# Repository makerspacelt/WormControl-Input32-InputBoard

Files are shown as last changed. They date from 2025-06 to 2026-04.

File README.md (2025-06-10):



---
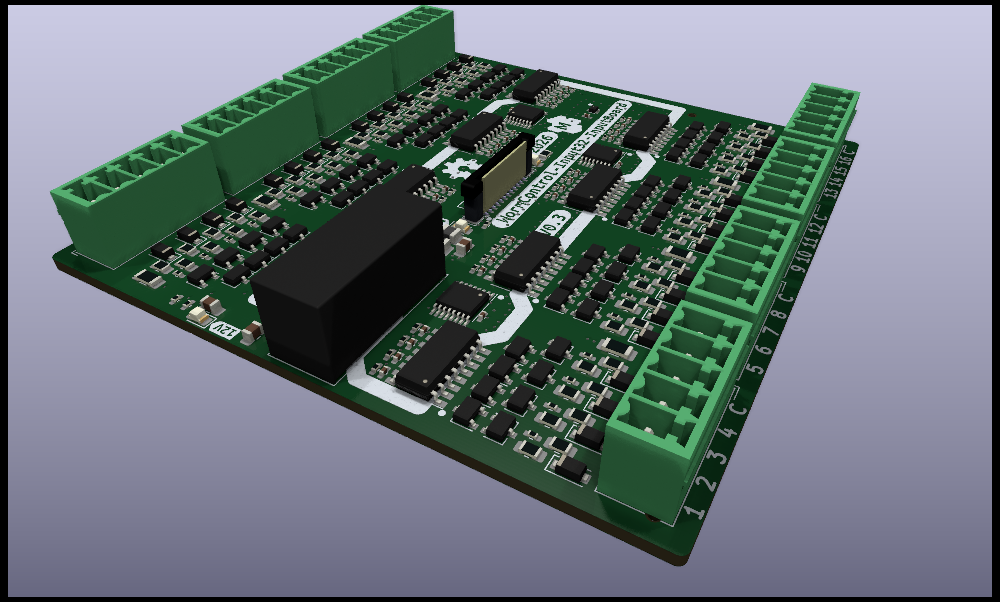
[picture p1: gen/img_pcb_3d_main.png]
PCB 3d main


WormControl Input32 InputBoard

NOTE: This is only a prototype now, so things might not work and everything might change 

Basic target features:

* 32 optically isolated binary inputs
* some kind of serial bus comunication
* 24V powered

Dev NOTE: before commit, run `./kibot.sh` to regenerate documentation, bom, gerbers and other assets.

* [schematics.pdf](gen/schematics.pdf)
* [pcb.pdf with dimensions](gen/pcb.pdf)
* [ibom.html](gen/single/ibom.html)

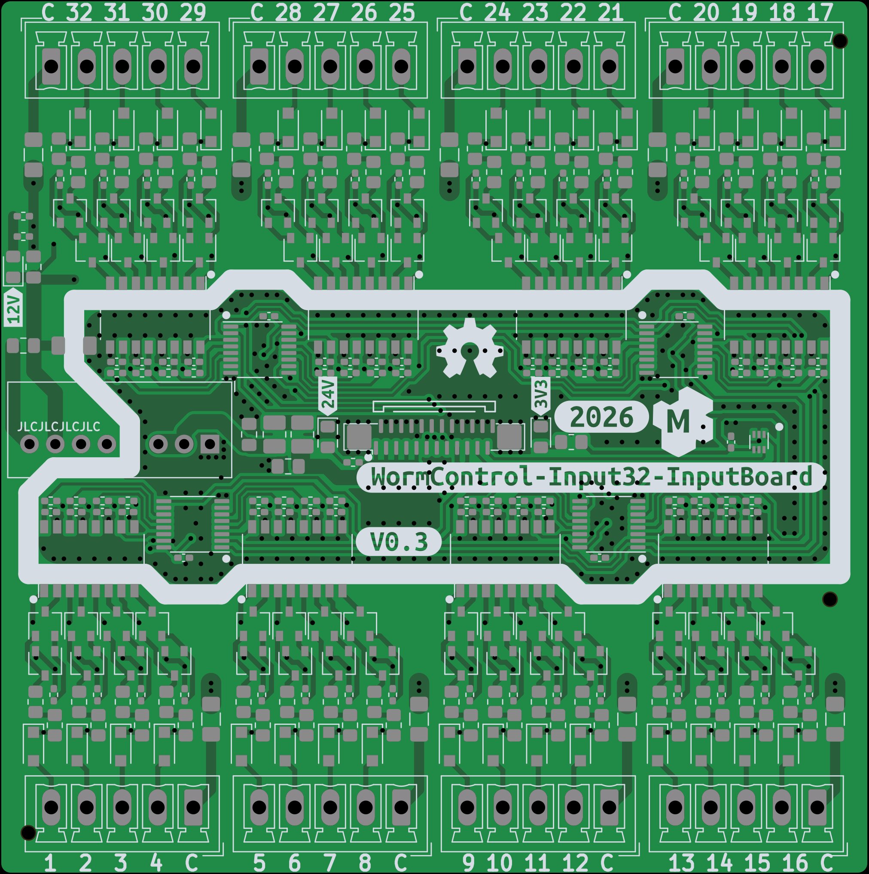
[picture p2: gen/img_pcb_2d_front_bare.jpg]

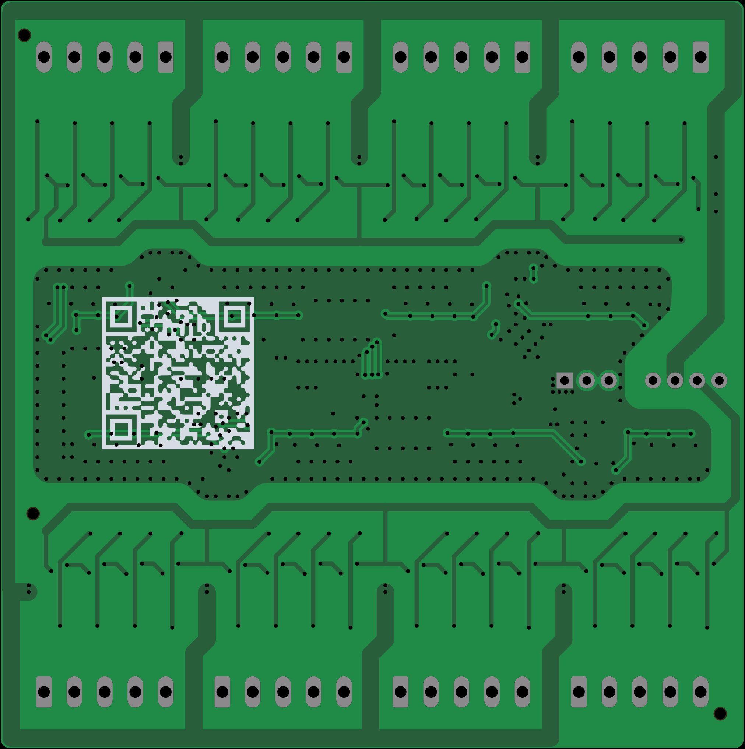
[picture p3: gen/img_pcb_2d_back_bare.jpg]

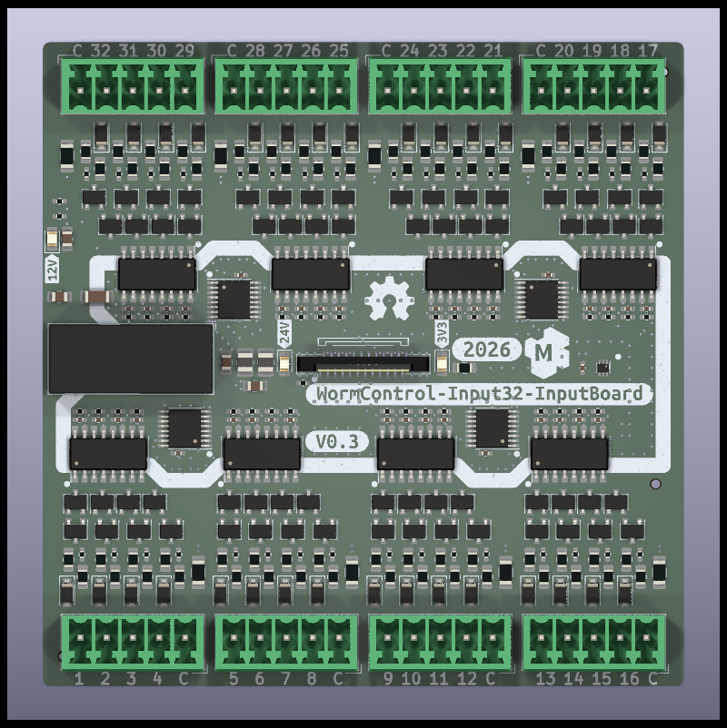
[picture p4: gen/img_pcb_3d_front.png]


---

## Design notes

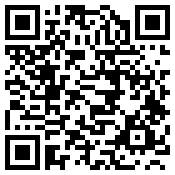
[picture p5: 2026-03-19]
gen/qr_link.png

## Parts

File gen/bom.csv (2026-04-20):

Row | Description | Part | References | Value | Footprint | Quantity Per PCB | Status | Datasheet | jlc-part-type | lcsc#
1 | Heatsink | Heatsink | BOM2,BOM3,BOM4,BOM5,BOM6,BOM7,BOM8,BOM9 | 1x5 screw plug |  | 8 |  | ~ | E | C560233
2 | Heatsink | Heatsink | BOM1 | FFC Cable 150mm reverse |  | 1 |  | https://www.lcsc.com/datasheet/C42434316.pdf | E | C42434316
3 | Unpolarized capacitor | C | C1,C2,C3,C4,C5,C6,C7,C8,C9,C10,C11,C12,C13,C14,C15,C16,C17,C18,C19,C20,C21,C22,C23,C24,C25,C26,C27,C28,C29,C30,C31,C32,C33,C39,C40,C41,C42 | 100n | C_0402_1005Metric_Pad0.74x0.62mm_HandSolder | 37 |  | ~ | B | C307331
4 | Unpolarized capacitor | C | C34,C35 | 10u/50v | C_0805_2012Metric_Pad1.18x1.45mm_HandSolder | 2 |  | ~ | B | C440198
5 | Unpolarized capacitor | C | C36 | 1n/2KV | C_1206_3216Metric_Pad1.33x1.80mm_HandSolder | 1 |  | ~ | B | C9196
6 | Unpolarized capacitor | C | C37,C38 | 22u/25v | C_0805_2012Metric_Pad1.18x1.45mm_HandSolder | 2 |  | ~ | B | C45783
7 | Light emitting diode | LED | D1,D30,D31 | GREEN | LED_0805_2012Metric_Pad1.15x1.40mm_HandSolder | 3 |  | ~ | B | C2297
8 | Diode, small symbol | D_Small | D2,D3,D4,D5,D6,D7,D8,D9,D10,D11,D12,D13,D14,D15,D16,D17,D18,D19,D20,D21,D22,D23,D24,D25,D26,D27,D28,D29,D32,D33,D34,D35 | SM4007PL | D_SOD-123F | 32 |  | ~ | B | C64898
9 | Resettable fuse, polymeric positive temperature coefficient | Polyfuse | F1,F2,F3,F4,F5,F6,F7,F8 | 50mA | Fuse_1206_3216Metric_Pad1.42x1.75mm_HandSolder | 8 |  | ~ | E | C2830235
10 | Generic connectable mounting pin connector, single row, 01x24, script generated (kicad-library-utils/schlib/autogen/connector/) | Conn_01x24_MountingPin | J1 | FFC Connector | AFC11-S24ICC-00 | 1 |  | ~ | E | C11075
11 | Generic screw terminal, single row, 01x05, script generated (kicad-library-utils/schlib/autogen/connector/) | Screw_Terminal_01x05 | J2,J3,J4,J5,J6,J7,J8,J9 | input_1x5 | PhoenixContact_MCV_1,5_5-G-3.5_1x05_P3.50mm_Vertical | 8 |  | ~ | E | C880557
12 | Inductor | L | L1,L2 | 3.3uH | L_1008_2520Metric_Pad1.43x2.20mm_HandSolder | 2 |  | ~ | E | C206304
13 | 3W, 1000 VDC Isolated DC/DC Converter Module, Remote Control, 24v in 12v out | 2412S-3WR2 | PS1 | 2412S-3WR2 | Converter_DCDC_XP_POWER-ITxxxxxS_THT | 1 |  | https://www.lcsc.com/datasheet/lcsc_datasheet_2410161204_YLPTEC-URB2412S-3WR2_C22749764.pdf | N | C22749764
14 | NPN transistor, base/emitter/collector | Q_NPN_BEC | Q1,Q2,Q3,Q4,Q5,Q6,Q7,Q8,Q9,Q10,Q11,Q12,Q13,Q14,Q15,Q16,Q17,Q18,Q19,Q20,Q21,Q22,Q23,Q24,Q25,Q26,Q27,Q28,Q29,Q30,Q31,Q32,Q33,Q34,Q35,Q36,Q37,Q38,Q39,Q40,Q41,Q42,Q43,Q44,Q45,Q46,Q47,Q48,Q49,Q50,Q51,Q52,Q53,Q54,Q55,Q56,Q57,Q58,Q59,Q60,Q61,Q62,Q63,Q64 | MMBTA44 | SOT-23W | 64 |  | ~ | E | C5381782
15 | Resistor | R | R10,R11,R12,R13,R26,R27,R28,R29,R42,R43,R44,R45,R58,R59,R60,R61,R74,R75,R76,R77,R90,R91,R92,R93,R106,R107,R108,R109,R125,R126,R127,R128 | 330R | R_0402_1005Metric_Pad0.72x0.64mm_HandSolder | 32 |  | ~ | B | C25104
16 | Resistor | R | R1 | 4k7 | R_0805_2012Metric_Pad1.20x1.40mm_HandSolder | 1 |  | ~ | B | C17673
17 | Resistor | R | R14,R15,R16,R17,R30,R31,R32,R33,R46,R47,R48,R49,R62,R63,R64,R65,R78,R79,R80,R81,R94,R95,R96,R97,R110,R111,R112,R113,R114,R115,R116,R129,R130,R131,R132 | 47k | R_0402_1005Metric_Pad0.72x0.64mm_HandSolder | 35 |  | ~ | B | C25792
18 | Resistor | R | R2,R3,R4,R5,R6,R7,R8,R9,R18,R19,R20,R21,R22,R23,R24,R25,R34,R35,R36,R37,R38,R39,R40,R41,R50,R51,R52,R53,R54,R55,R56,R57,R66,R67,R68,R69,R70,R71,R72,R73,R82,R83,R84,R85,R86,R87,R88,R89,R98,R99,R100,R101,R102,R103,R104,R105,R117,R118,R119,R120,R121,R122,R123,R124 | 220k | R_0805_2012Metric_Pad1.20x1.40mm_HandSolder | 64 |  | ~ | B | C17556
19 | Shift Register, 8-bit, Parallel Load | 74HC165 | U1,U2,U4,U5 | 74HC165 | TSSOP-16_4.4x5mm_P0.65mm | 4 |  | https://assets.nexperia.com/documents/data-sheet/74HC_HCT165.pdf | E | C26159248
20 | Quad AC/DC Optocoupler, Vce 35V, CTR 20%, DIP16 | LTV-844 | U6,U7,U8,U9,U10,U11,U12,U13 | LTV-244-GB-G | SOP-16_4.4x10.4mm_P1.27mm | 8 |  | https://jlcpcb.com/api/file/downloadByFileSystemAccessId/8589836176828751872 | E | C5143796
21 | Digital Temperature Sensor, +/- 3 °C, low-Power, SMBus, 12 bit, Two-Wire Serial Interface, SOT-563 | TMP102xxDRL | U3 | TMP102 | SOT-563 | 1 |  | https://www.ti.com/lit/ds/symlink/tmp102.pdf | E | C99269

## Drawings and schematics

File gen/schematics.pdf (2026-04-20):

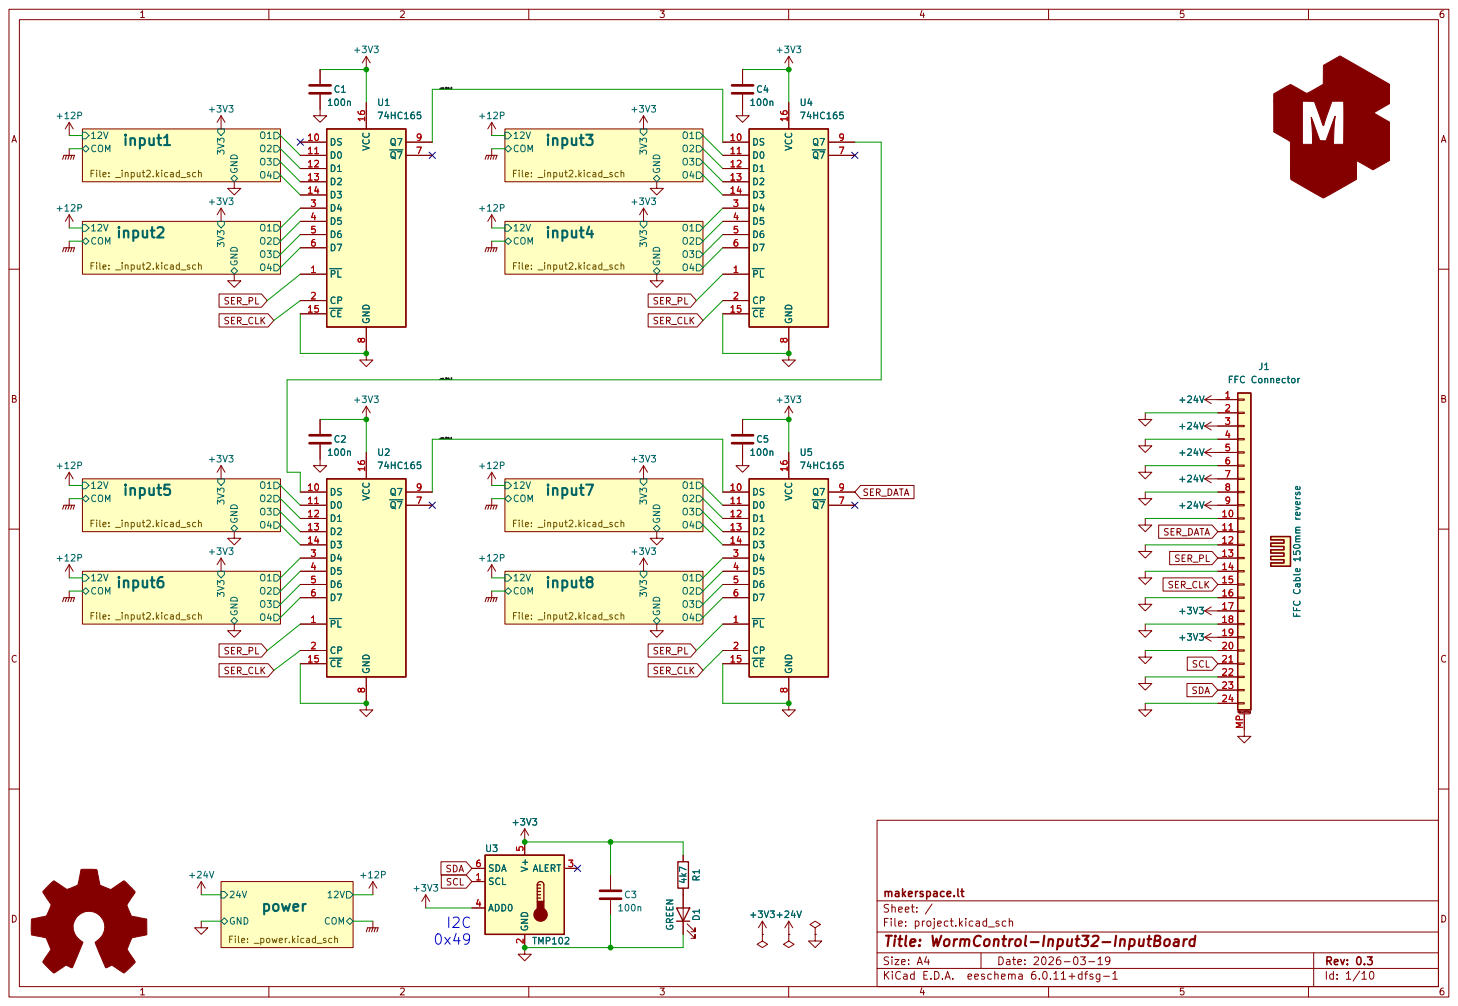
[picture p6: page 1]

Id: 1/10 Title: WormControl-Input32-InputBoard

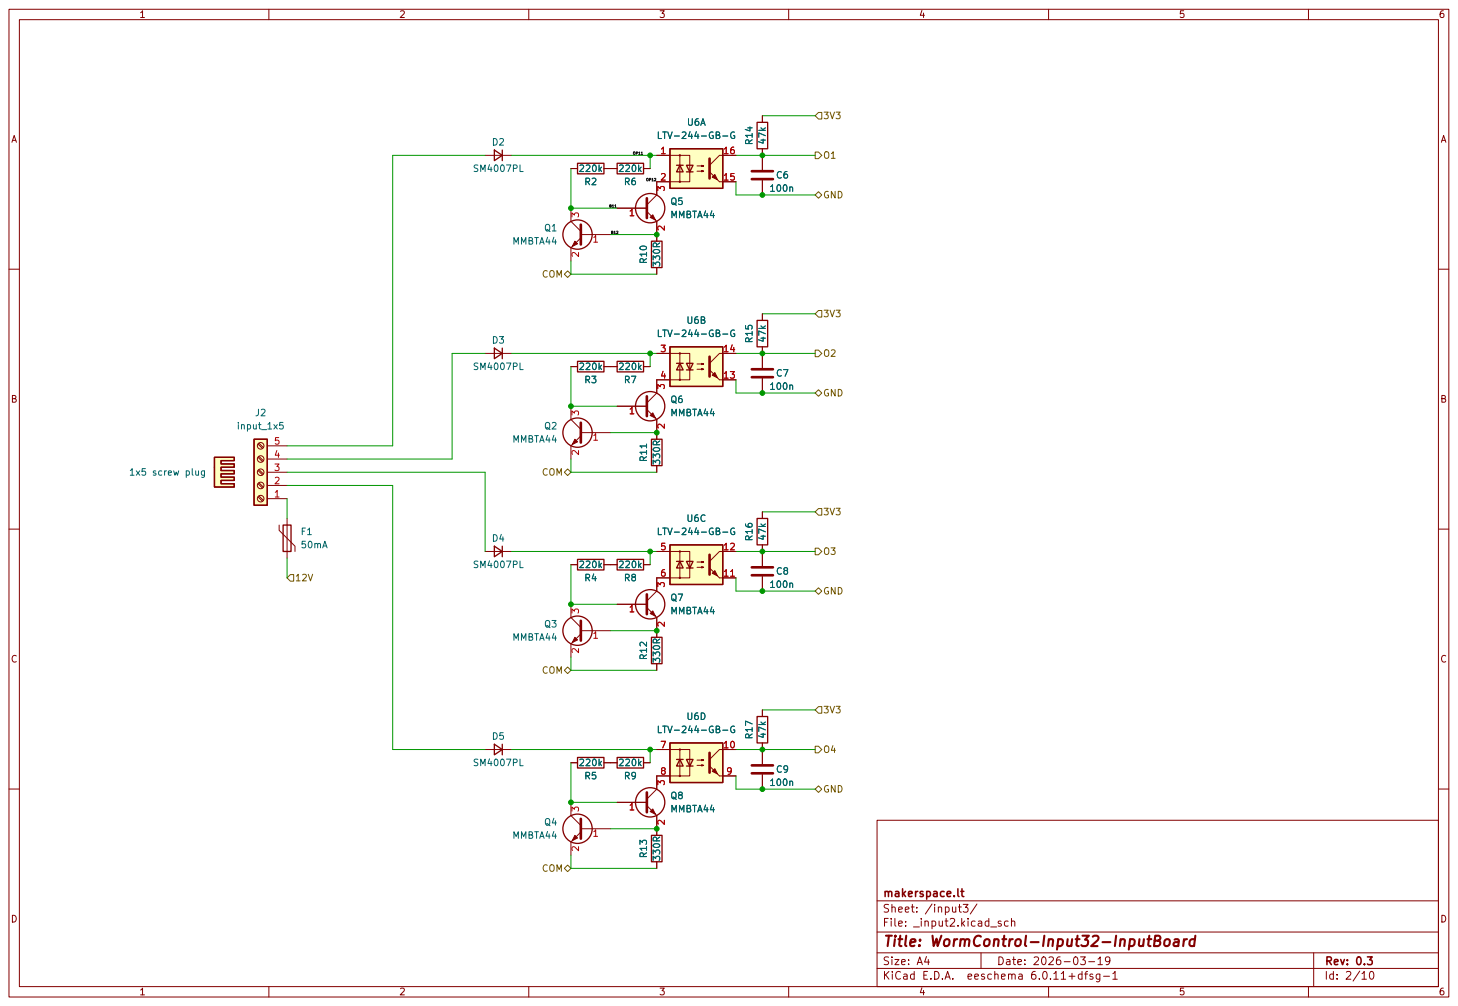
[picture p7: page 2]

File: _input2.kicad_sch Sheet: /input3/
Id: 2/10 Title: WormControl-Input32-InputBoard

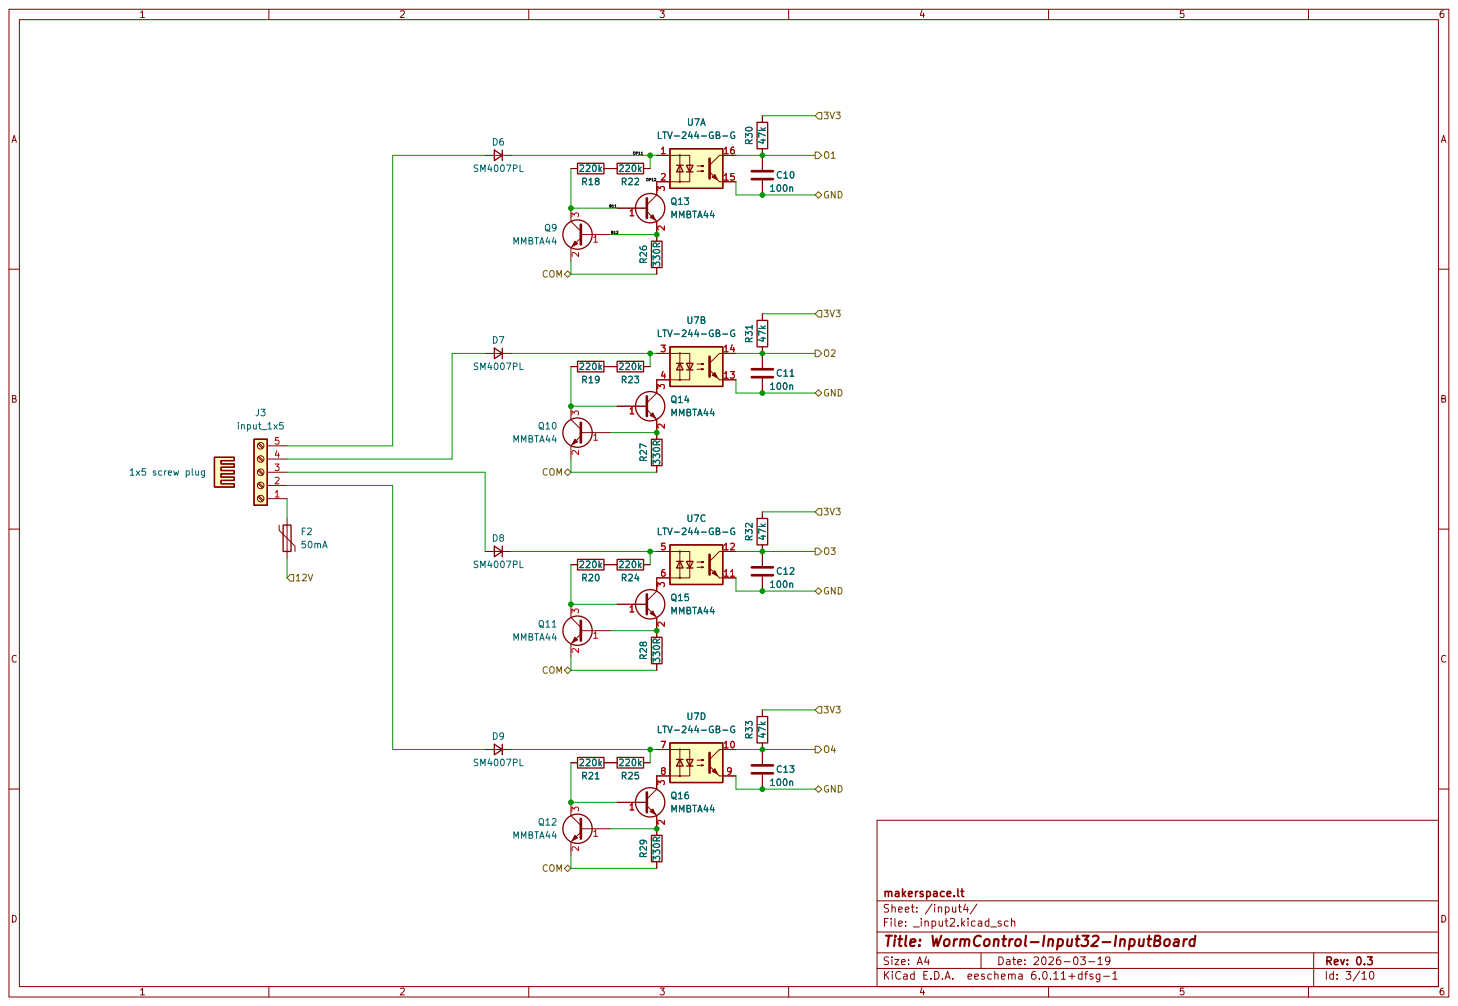
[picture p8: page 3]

makerspace.lt
File: _input2.kicad_sch Sheet: /input4/
Id: 3/10 Title: WormControl-Input32-InputBoard

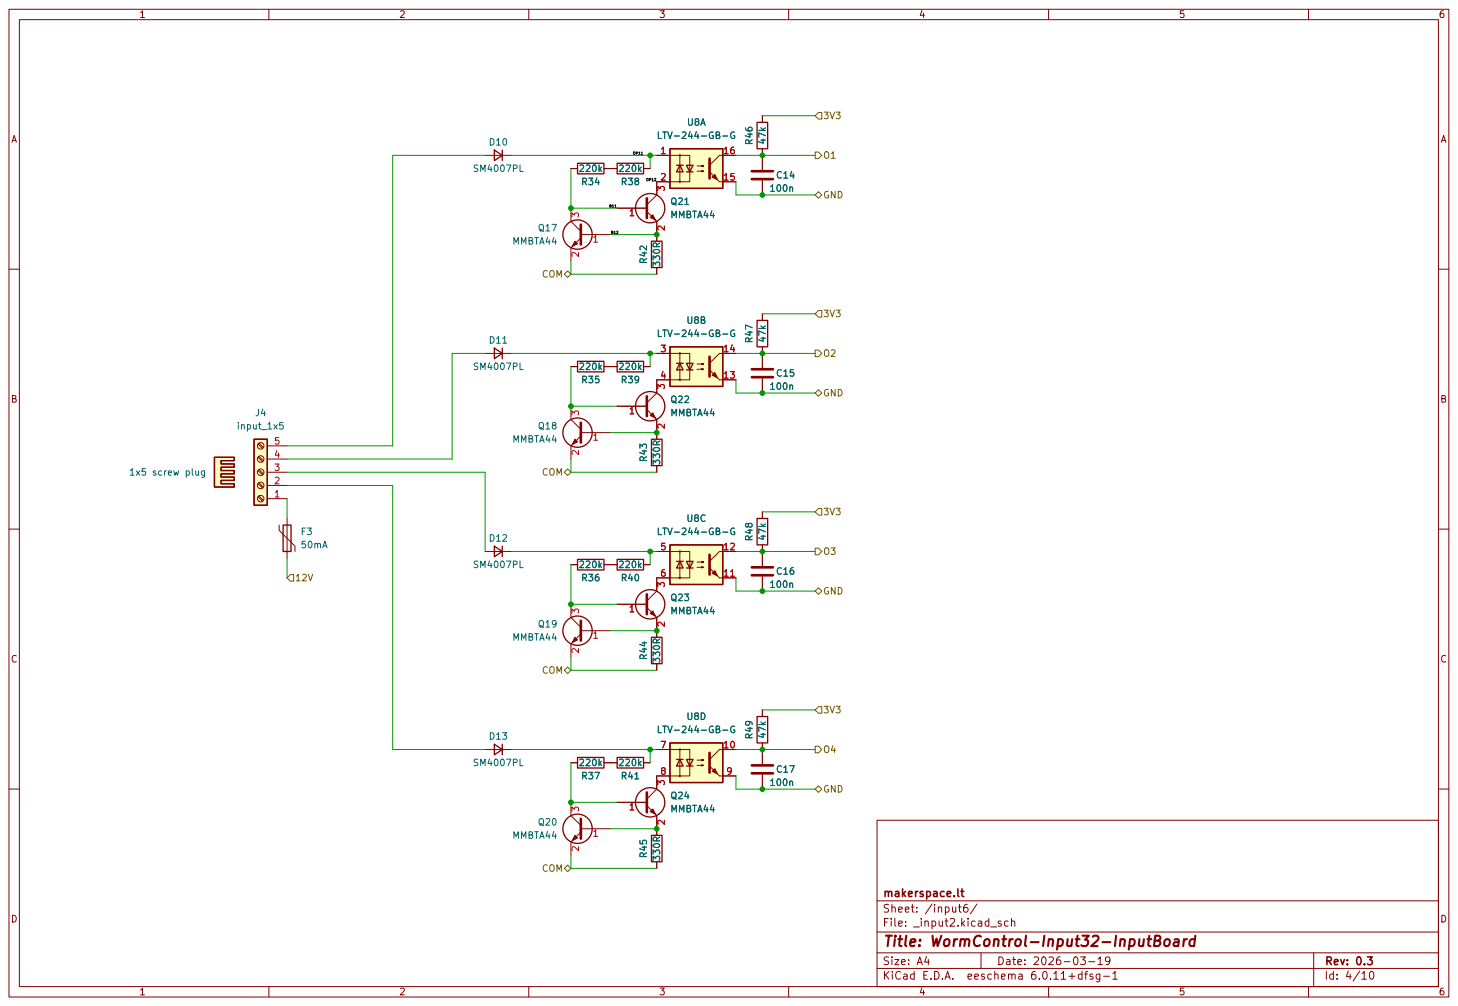
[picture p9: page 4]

makerspace.lt
File: _input2.kicad_sch Sheet: /input6/
Id: 4/10 Title: WormControl-Input32-InputBoard

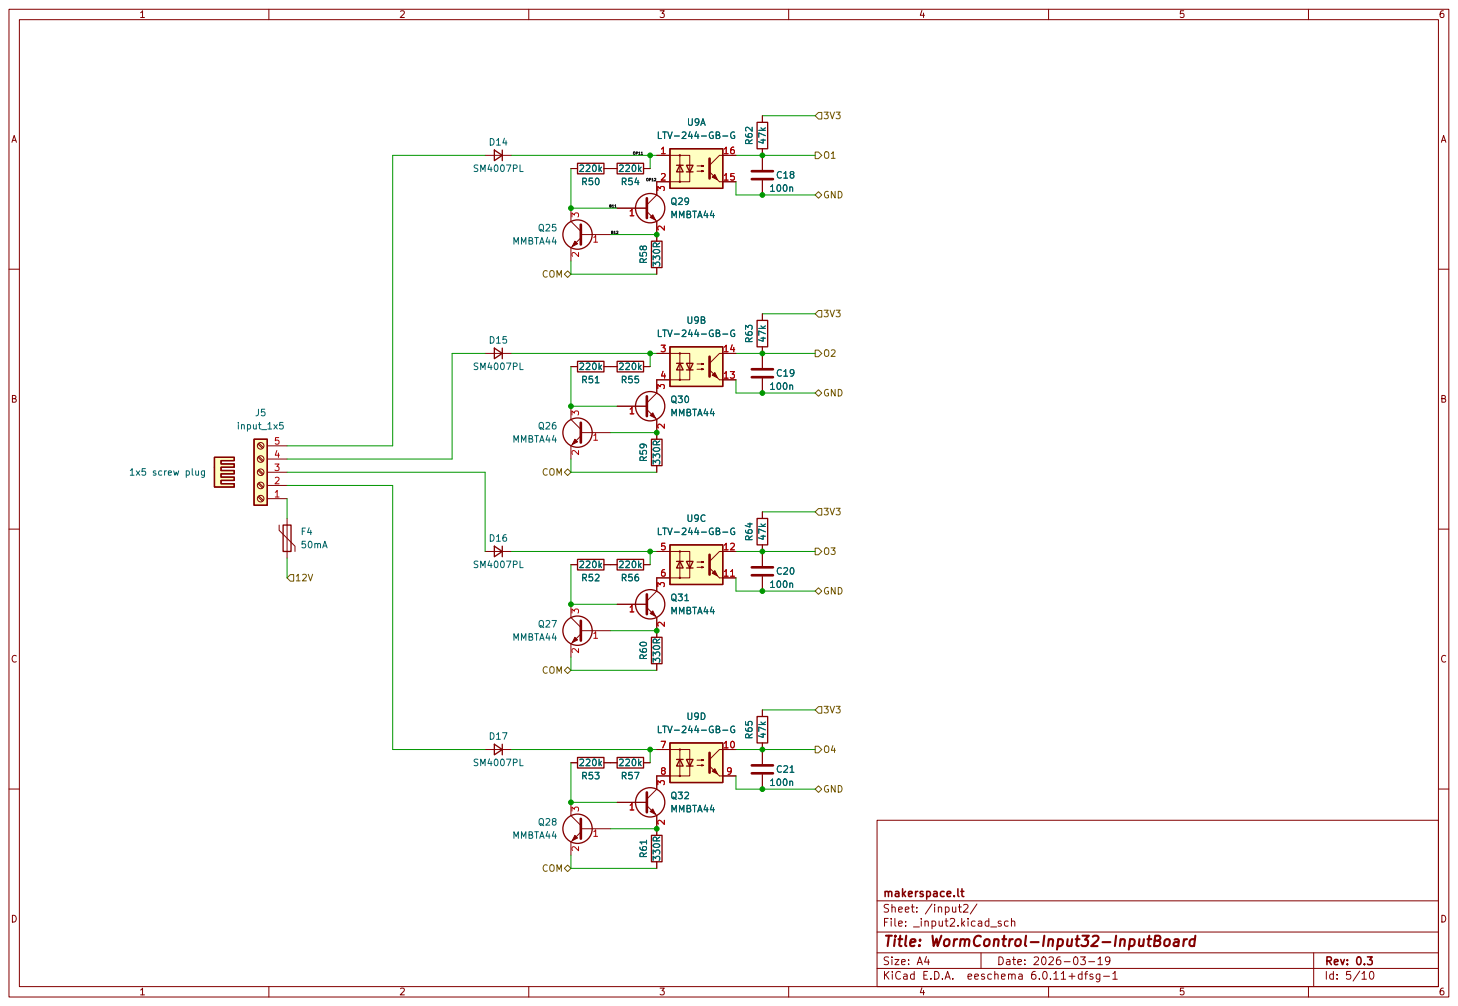
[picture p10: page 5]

makerspace.lt
File: _input2.kicad_sch Sheet: /input2/
Id: 5/10 Title: WormControl-Input32-InputBoard

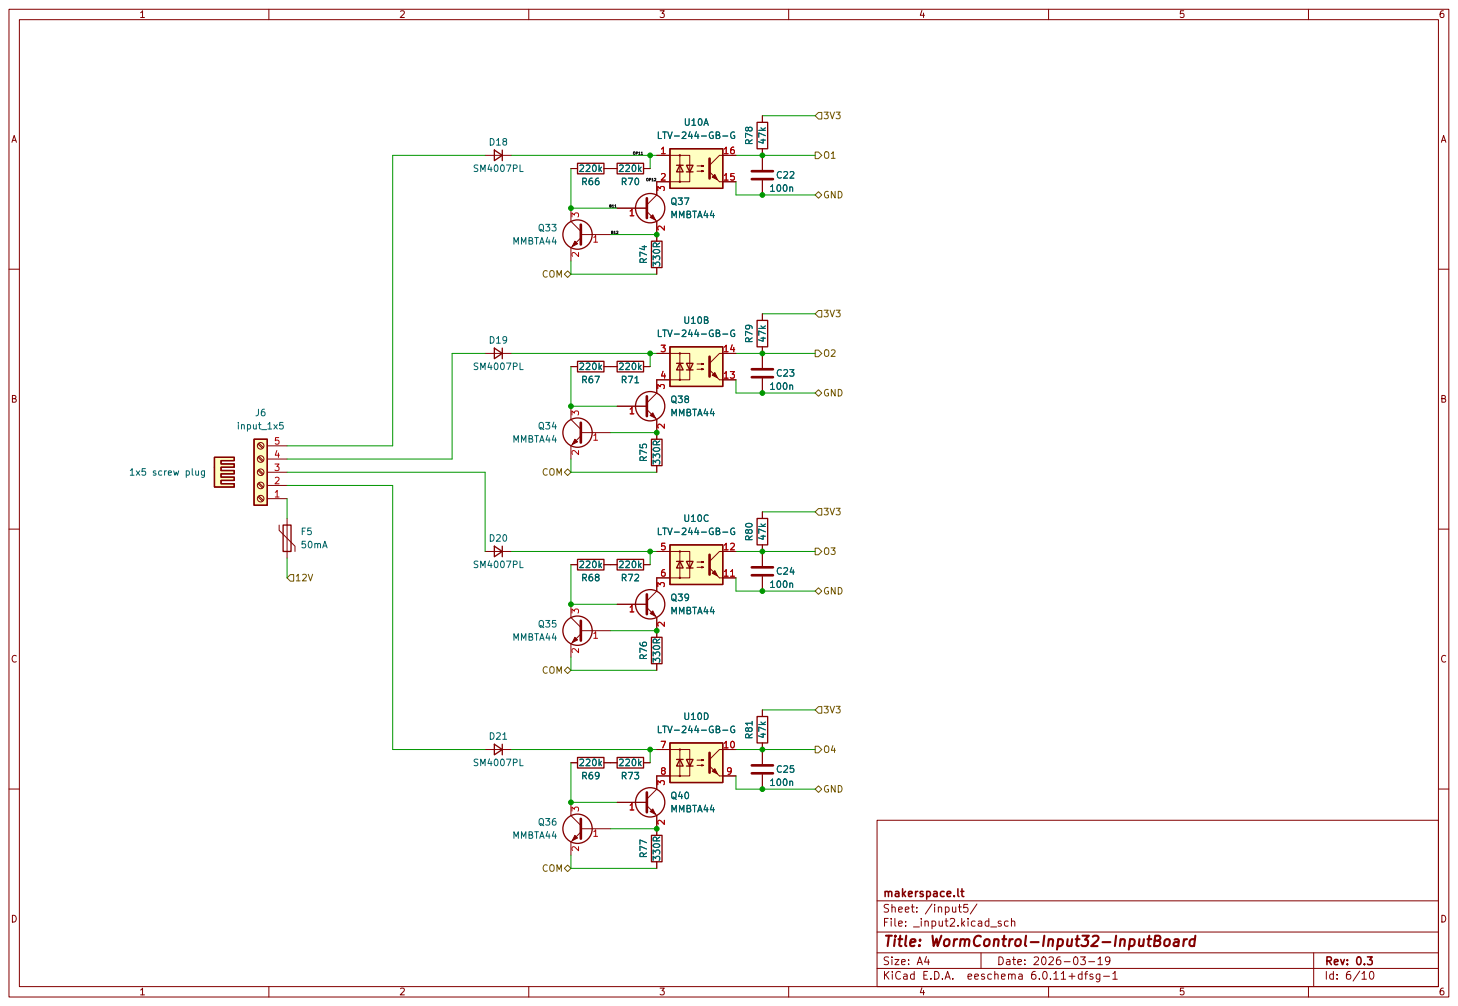
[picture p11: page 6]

makerspace.lt
File: _input2.kicad_sch Sheet: /input5/
Id: 6/10 Title: WormControl-Input32-InputBoard

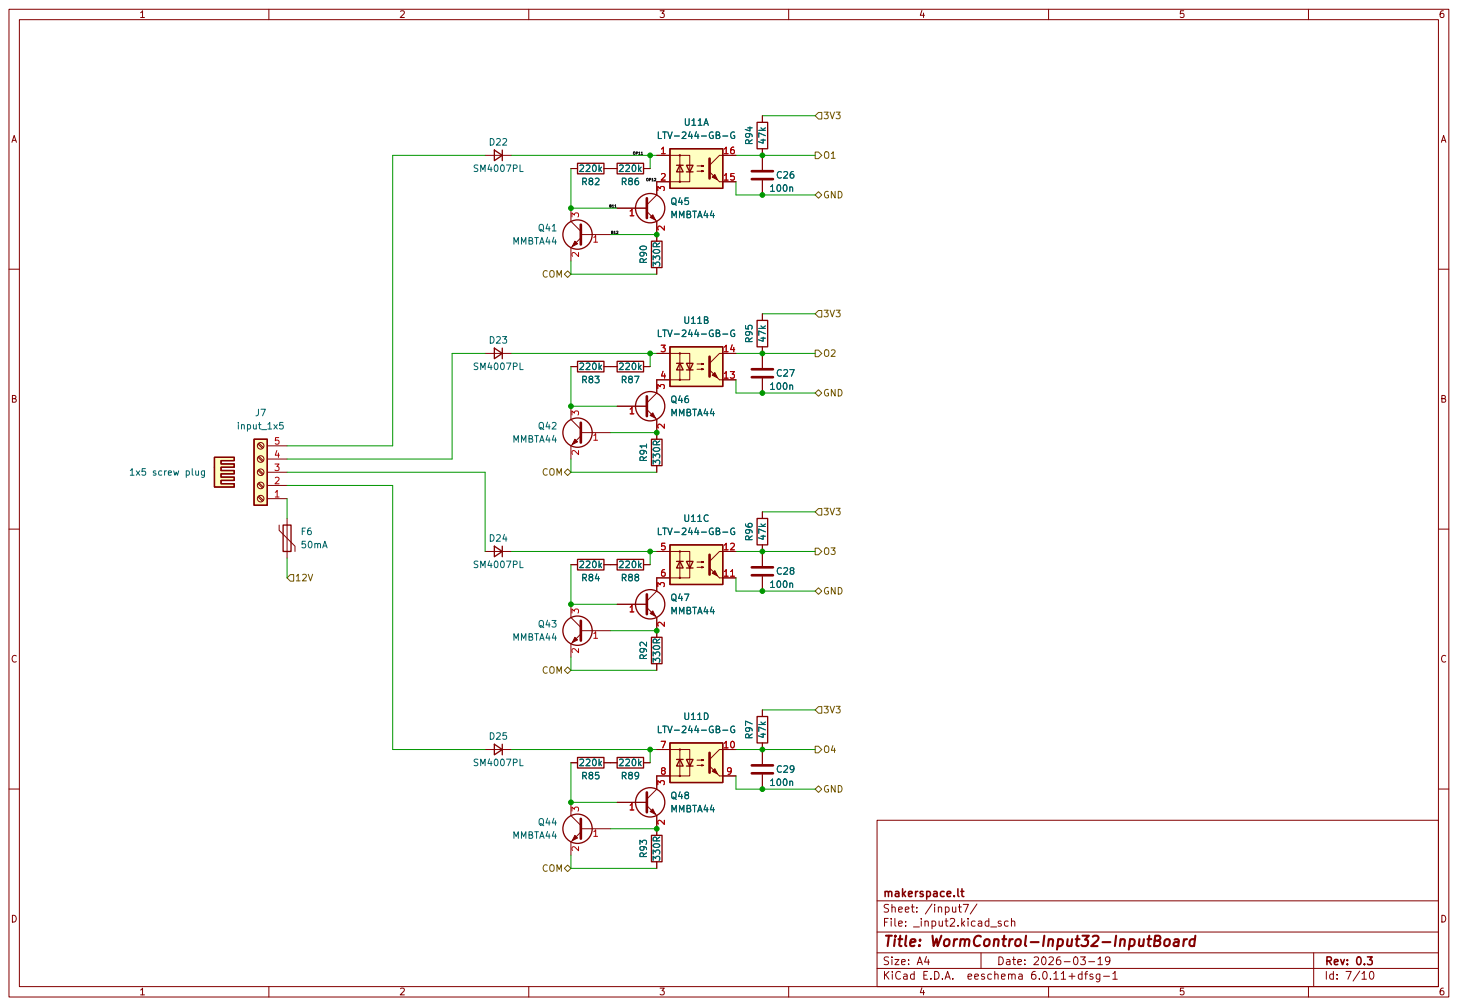
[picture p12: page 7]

makerspace.lt
File: _input2.kicad_sch Sheet: /input7/
Id: 7/10 Title: WormControl-Input32-InputBoard

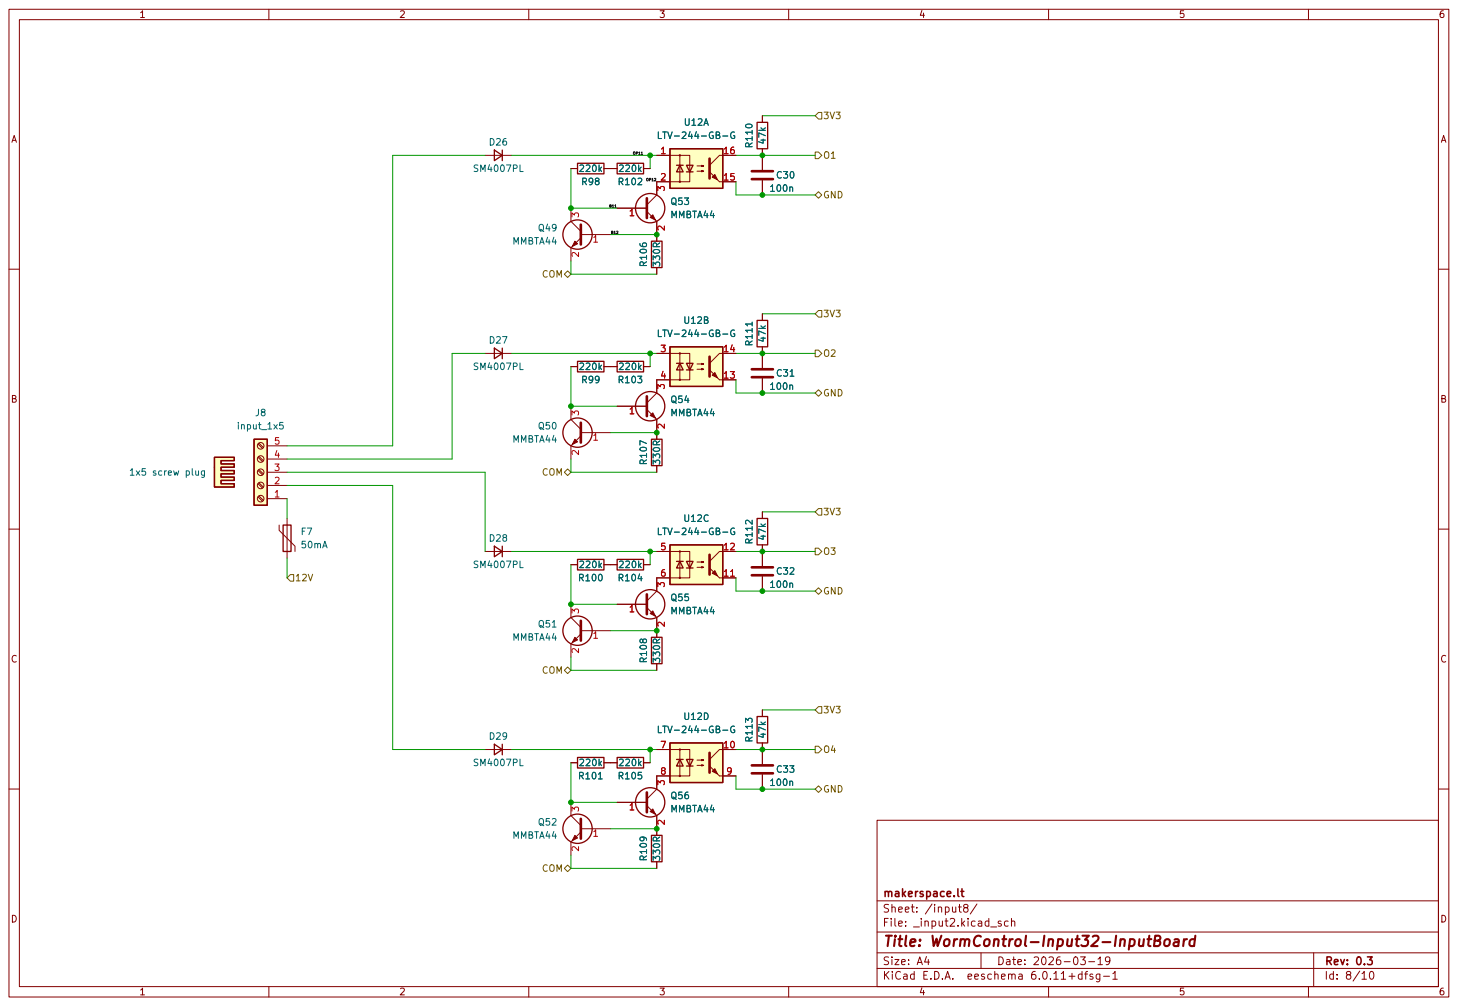
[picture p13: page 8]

makerspace.lt
File: _input2.kicad_sch Sheet: /input8/
Id: 8/10 Title: WormControl-Input32-InputBoard

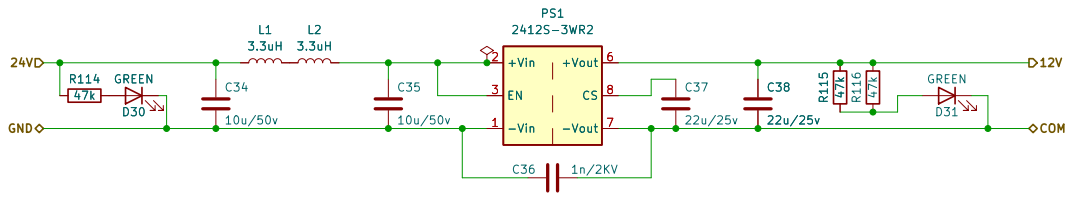
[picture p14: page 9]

File: _power.kicad_sch Sheet: /power/
Id: 10/10 Title: WormControl-Input32-InputBoard

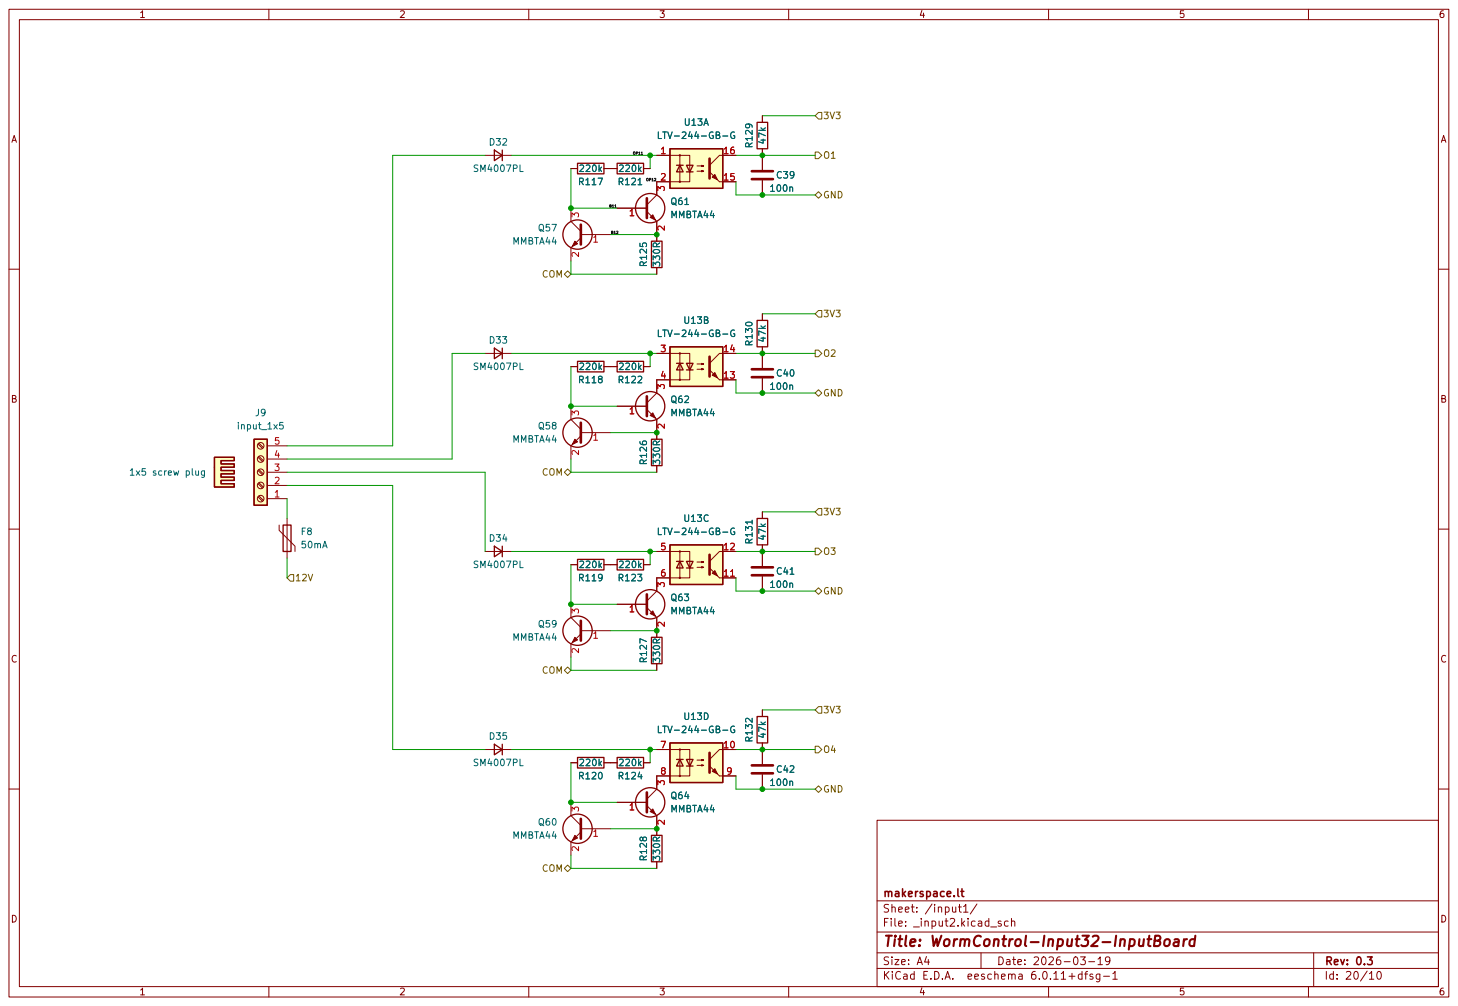
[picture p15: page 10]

makerspace.lt
File: _input2.kicad_sch Sheet: /input1/
Id: 20/10 Title: WormControl-Input32-InputBoard

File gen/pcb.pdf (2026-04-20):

85.5 mm

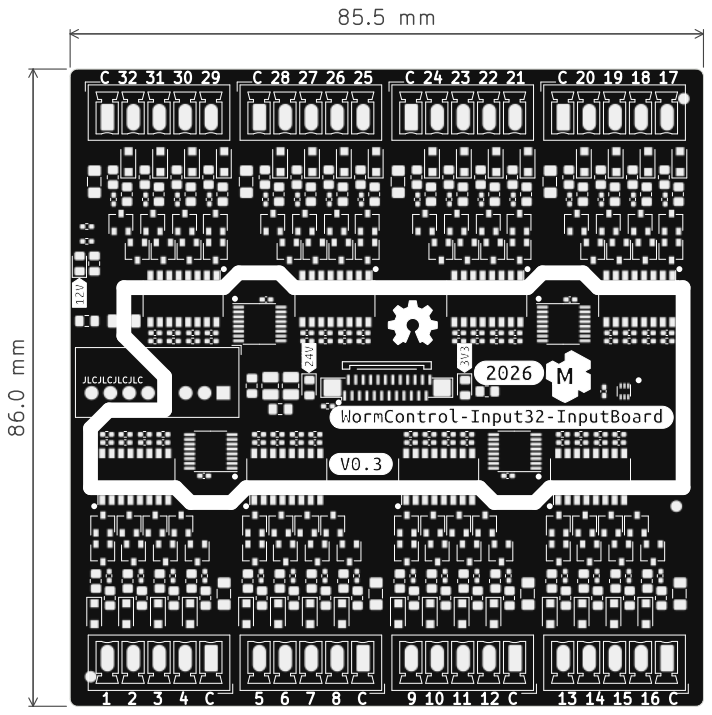
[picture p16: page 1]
JLCJLCJLCJLC

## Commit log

2025-06-10 Initial version for testing
    [_bom.csv, _input.kicad_sch, _input2.kicad_sch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]
2025-07-04 bom fixes
    [_bom.csv, _input3.kicad_sch, bom.csv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]
2026-01-29 refactoring everything to use selected input type
    [_bom.csv, _input.kicad_sch, _input2.kicad_sch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]
2026-02-12 moving ffc connector to align with other boards
    [project.kicad_pcb]
2026-02-12 updating kibot and generatables
    [bom_lcsc.csv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]
2026-03-19 replacing thermometer
    * Switching to TMP102 as TMP101 is no longer available
    * bumping up version
    [_bom.csv, _input2.kicad_sch, _power.kicad_sch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]
2026-04-20 fixing tmp102 pinout
    [_bom.csv, _input2.kicad_sch, _power.kicad_sch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]
